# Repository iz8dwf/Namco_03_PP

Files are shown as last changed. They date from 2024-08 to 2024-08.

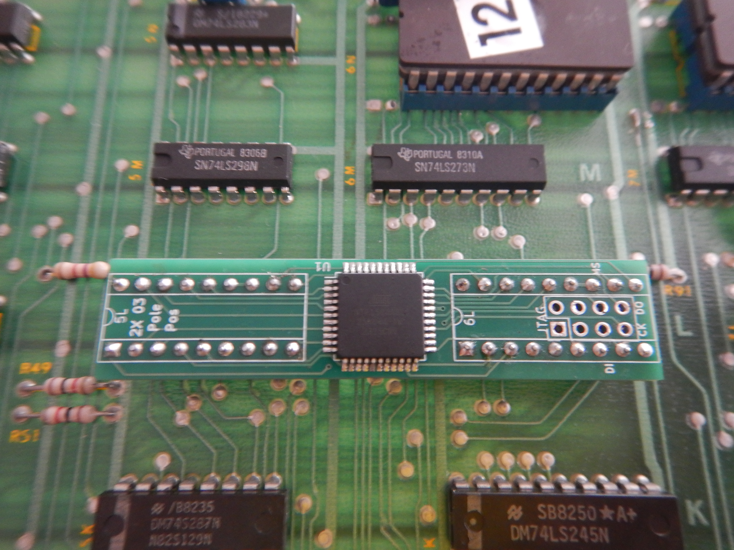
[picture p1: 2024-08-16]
images/DSCN4794.JPG

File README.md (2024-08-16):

# Namco_03_PP
Namco 03xx custom IC replacement for Pole Position video PCB

This daughterboard replaces the two 03XX custom ICs at 5L and 6L on
a Pole Position (or Pole Position II) Video PCB. It uses a single atf1504
CPLD to implement partially both 03XX ICs. Original 03XX are 6 bits wide, 
4 bits deep shift register with configurable depth. See the CPLD source file
for more information. Pole Position only uses 4 bits of the 6 bits and
the clock pin of both ICs is driven by the same signal, so that's
what I've implemented. A general purpose replacement with full 6 bits can 
in theory be implemented on a single atf1502 but I haven't tested it.

(Fun) Fact: one original 03XX IC has been reverse engineered with the help of
a Commodore PET 3032 machine using its 8 bit bi-directional user port and a few
Basic programs. These are "static" ICs so clock can be toggled even at a few seconds
intervals if needed.

THE JTAG PINOUT IS NOT STANDARD!

USE AT YOUR OWN RISK

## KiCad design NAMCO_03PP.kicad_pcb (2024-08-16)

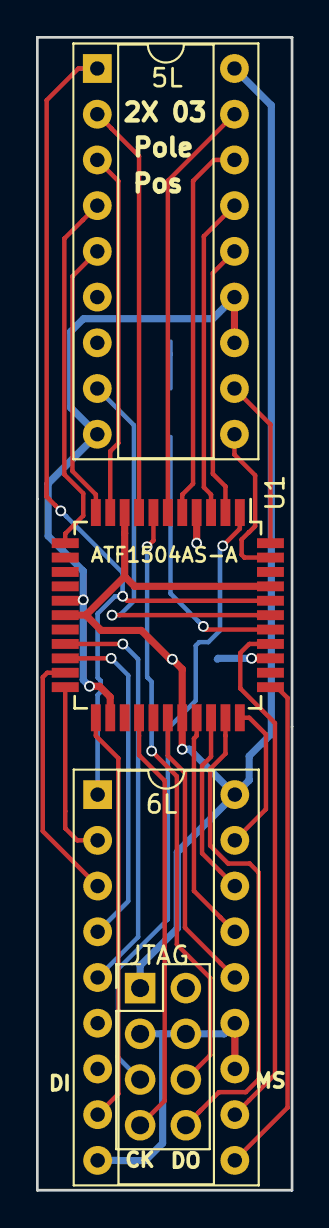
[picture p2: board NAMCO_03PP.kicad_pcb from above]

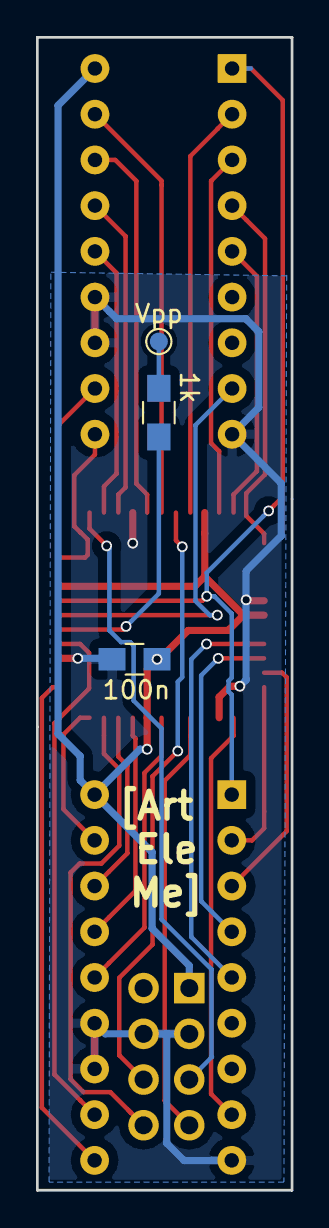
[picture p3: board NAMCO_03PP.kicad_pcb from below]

Board: 2 copper layers, 14.1 x 64.0 mm, 7 parts (3 on the bottom side), 31 nets.

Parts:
5L, 6L: DIP18; DIP-18_W7.62mm_Socket
C1: 100n; C_0805_HandSoldering
J1: JTAG; Pin_Header_Straight_2x04_Pitch2.54mm
J2: Vpp; Test_Point_Pad_d1.0mm
R1: 1k; R_0805_HandSoldering
U1: ATF1504AS-A; TQFP-44_10x10mm_Pitch0.8mm

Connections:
/I10: 5L.2, U1.8
/I11: 5L.3, U1.10
/I12: 5L.4, U1.12
/I13: 5L.5, U1.11
/I20: 6L.2, U1.22
/I21: 6L.3, U1.21
/I22: 6L.4, U1.20
/I23: 6L.5, U1.19
/O10: 5L.17, U1.6
/O11: 5L.16, U1.5
/O12: 5L.15, U1.3
/O13: 5L.14, U1.2
/O20: 6L.17, U1.33
/O21: 6L.16, U1.31
/O22: 6L.15, U1.30
/O23: 6L.14, U1.28
/OUT_SEL1: 5L.8, U1.39
/OUT_SEL2: 6L.8, U1.23
/QSL10: 5L.10, U1.43
/QSL11: 5L.11, U1.44
/QSL20: 6L.10, U1.34
/QSL21: 6L.11, U1.37
/~6M: 5L.1, 6L.1, U1.40
GND: 5L.9, 5L.12, 5L.13, 6L.9, 6L.12, 6L.13, C1.2, J1.3, J1.4, U1.4, U1.16, U1.24, U1.36
unnamed: J1.5, U1.1
unnamed: J1.6, U1.7
unnamed: J1.7, U1.26
unnamed: J1.8, U1.32
unnamed: J2.1, R1.1
unnamed: R1.2, U1.38
VCC: 5L.18, 6L.18, C1.1, J1.1, U1.9, U1.17, U1.29, U1.41
